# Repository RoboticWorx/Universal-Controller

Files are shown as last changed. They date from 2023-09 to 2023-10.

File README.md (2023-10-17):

# Universal_Controller
Files for my Universal Remote Controller project. 

***(Remember, you can download anything you'd like for yourself but you CAN'T sell or redistribute it. All my work is licensed, thanks!)***

Be sure to go to www.roboticworx.io for detailed tutorials on a variety of projects! Thanks for reading and happy making!

Best regards, 
Justin

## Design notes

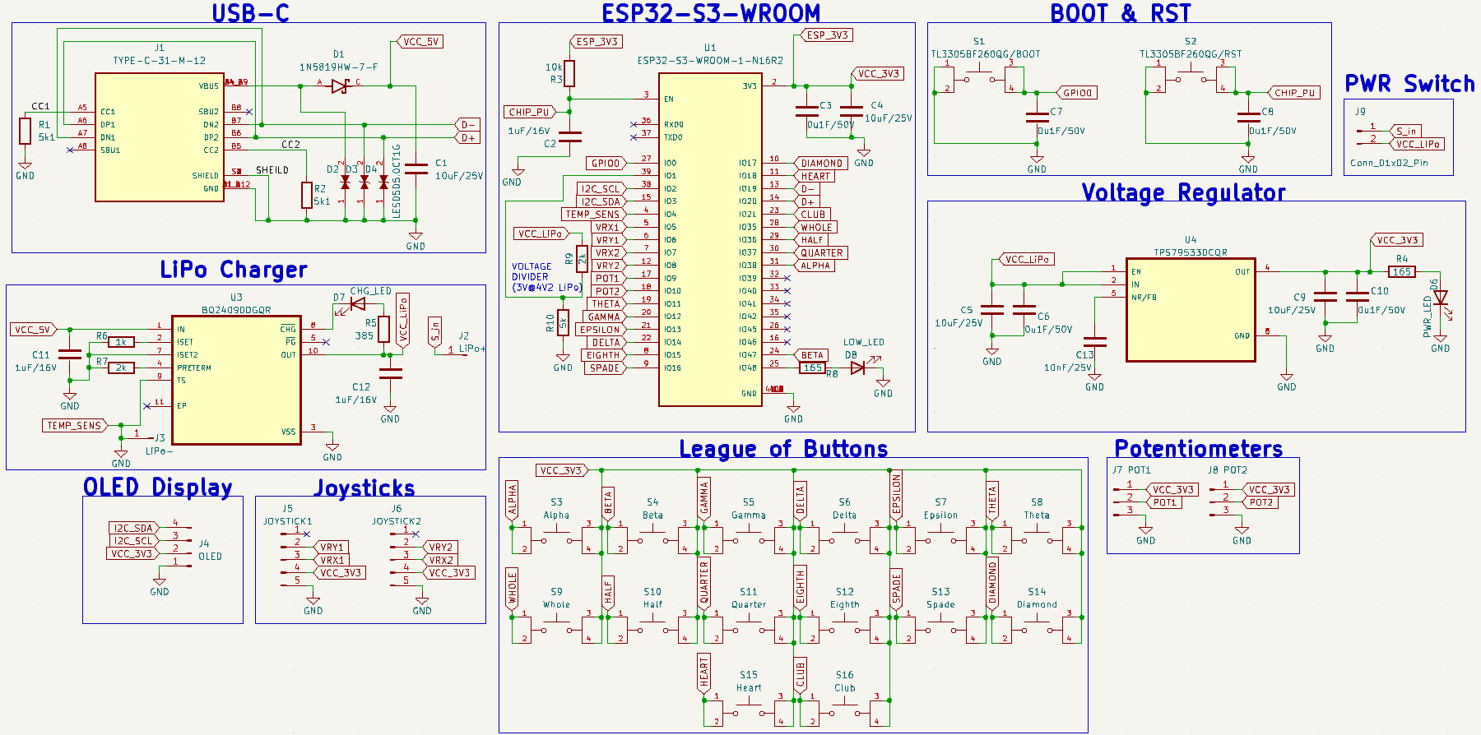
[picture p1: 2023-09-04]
Image_Schematic.png

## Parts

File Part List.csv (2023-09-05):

 | From Digikey
# | QUANTITY | PART NUMBER | MANUFACTURER PART NUMBER | DESCRIPTION | UNIT PRICE
1 | 1 | 296-13810-1-ND | TPS79533DCQR | IC REG LIN 3.3V 500MA SOT223-6 | $2.68
2 | 1 | 478-KGM15AR71H103KTCT-ND | KGM15AR71H103KT | CAP CER 10000PF 50V X7R 0603 | $0.01
3 | 1 | 296-38875-1-ND | BQ24090DGQR | IC BATT CHG LI-ION 1CELL 10MSOP | $1.26
4 | 16 | EG5354CT-ND | TL3305BF260QG | SWITCHES | $0.23
5 | 2 | RG16P2.0KBCT-ND | RG1608P-202-B-T5 | RES SMD 2K OHM 0.1% 1/10W 0603 | $0.35
6 | 1 | 13-RT0603BRE075KLCT-ND | RT0603BRE075KL | RES 5K OHM 0.1% 1/10W 0603 | $0.28
7 | 1 | 754-1721-ND | WP710A10ID5V | LED RED DIFFUSED T-1 T/H | $0.33
8 | 1 | 13-RC0603FR-13390RLCT-ND | RC0603FR-13390RL | RES 390 OHM 1% 1/10W 0603 | $0.01
9 | 1 | 1965-ESP32-S3-WROOM-1-N4R8CT-ND | ESP32-S3-WROOM-1-N4R8 | RF TXRX MODULE BT PCB TRACE SMD | $3.35
10 | 3 | 1276-1019-1-ND | CL10B105KO8NNNC | CAP CER 1UF 16V X7R 0603 | $0.01
11 | 2 | P5.1KDACT-ND | ERA-6AEB512V | RES 5.1K OHM 0.1% 1/8W 0805 | $0.14
12 | 2 | 13-RC0805FR-13180RLCT-ND | RC0805FR-13180RL | RES 180 OHM 1% 1/8W 0805 | $0.01
13 | 4 | 1276-1096-1-ND | CL21A106KOQNNNE | CAP CER 10UF 16V X5R 0805 | $0.03
14 | 1 | RNCP0603FTD10K0CT-ND | RNCP0603FTD10K0 | 10kohm Resistor RES 10K OHM 1% 1/8W 0603 | $0.02
15 | 1 | RNCP0603FTD1K00CT-ND | RNCP0603FTD1K00 | RES 1K OHM 1% 1/8W 0603 | $0.10
 | From LCSC Electronics
16 | 5 | C513772 | CS1005X7R104K500NR | 50V 100nF Capacitor ±10% 0402 Multilayer Ceramic Capacitors MLCC - SMD/SMT ROHS | $0.00
17 | 1 | C82544 | 1N5819HW-7-F | Diode 40V 450mV@1A 1A SOD-123 Schottky Barrier Diodes (SBD) ROHS | $0.02
18 | 3 | C383211 | LESD5D5.0CT1G | Zener Diode 5.6V 18.6V 5V Bi-Directional SOD-523 ESD Protection Devices ROHS | $0.02
19 | 1 | C2765186 | TYPE-C 16PIN 2MD(073) | USB-C Connector 5A 1 Surface Mount 16P Female -25℃~+85℃ Type-C SMD USB Connectors ROHS | $0.05
 | From Amazon
 | In article BOM

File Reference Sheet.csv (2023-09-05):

Reference | Value | Footprint | Datasheet | SNAPEDA_PN | STANDARD | Qty
C1, C4, C5, C9 | 10uF/16V | Capacitor_SMD:C_0805_2012Metric_Pad1.18x1.45mm_HandSolder | ~ |  |  | 4
C2, C11, C12 | 1uF/16V | Capacitor_SMD:C_0603_1608Metric_Pad1.08x0.95mm_HandSolder | ~ |  |  | 3
C3, C6-C8, C10 | 0u1F/50V | Capacitor_SMD:C_0201_0603Metric_Pad0.64x0.40mm_HandSolder | ~ |  |  | 5
C13 | 10nF/25V | Capacitor_SMD:C_0201_0603Metric_Pad0.64x0.40mm_HandSolder | ~ |  |  | 1
D1 | 1N5819HW-7-F | MyParts:SOD3715X145N |  |  | IPC-7351B | 1
D2-D4 | LESD5D5.0CT1G | MyParts:TVS_LESD5D5.0CT1G |  |  | Manufacturer Recommendations | 3
D6 | PWR_LED | LED_THT:LED_D3.0mm | ~ |  |  | 1
D7 | CHG_LED | LED_THT:LED_D3.0mm | ~ |  |  | 1
D8 | LOW_LED | LED_THT:LED_D3.0mm | ~ |  |  | 1
J1 | TYPE-C-31-M-12 | MyParts:HRO_TYPE-C-31-M-12 |  | TYPE-C-31-M-12 | Manufacturer Recommendations | 1
J2 | LiPo+ | Connector_PinHeader_2.54mm:PinHeader_1x01_P2.54mm_Vertical | ~ |  |  | 1
J3 | LiPo- | Connector_PinHeader_2.54mm:PinHeader_1x01_P2.54mm_Vertical | ~ |  |  | 1
J4 | OLED | Connector_PinHeader_2.54mm:PinHeader_1x04_P2.54mm_Vertical | ~ |  |  | 1
J5 | JOYSTICK1 | Connector_PinHeader_2.54mm:PinHeader_1x05_P2.54mm_Vertical | ~ |  |  | 1
J6 | JOYSTICK2 | Connector_PinHeader_2.54mm:PinHeader_1x05_P2.54mm_Vertical | ~ |  |  | 1
J7 | POT1 | Connector_PinHeader_2.54mm:PinHeader_1x03_P2.54mm_Vertical | ~ |  |  | 1
J8 | POT2 | Connector_PinHeader_2.54mm:PinHeader_1x03_P2.54mm_Vertical | ~ |  |  | 1
J9 | Conn_01x02_Pin | Connector_PinHeader_2.54mm:PinHeader_1x02_P2.54mm_Vertical | ~ |  |  | 1
R1, R2 | 5k1 | Resistor_SMD:R_0805_2012Metric_Pad1.20x1.40mm_HandSolder | ~ |  |  | 2
R3 | 10k | Resistor_SMD:R_0805_2012Metric_Pad1.20x1.40mm_HandSolder | ~ |  |  | 1
R4, R8 | 165 | Resistor_SMD:R_0603_1608Metric_Pad0.98x0.95mm_HandSolder | ~ |  |  | 2
R5 | 385 | Resistor_SMD:R_0603_1608Metric_Pad0.98x0.95mm_HandSolder | ~ |  |  | 1
R6 | 1k | Resistor_SMD:R_0805_2012Metric_Pad1.20x1.40mm_HandSolder | ~ |  |  | 1
R7, R9 | 2k | Resistor_SMD:R_0805_2012Metric_Pad1.20x1.40mm_HandSolder | ~ |  |  | 2
R10 | 5k | Resistor_SMD:R_0805_2012Metric_Pad1.20x1.40mm_HandSolder | ~ |  |  | 1
S1 | TL3305BF260QG/BOOT | MyParts:SW_TL3305BF260QG |  | TL3305BF260QG | Manufacturer Recommendations | 1
S2 | TL3305BF260QG/RST | MyParts:SW_TL3305BF260QG |  | TL3305BF260QG | Manufacturer Recommendations | 1
S3 | Alpha (All these switches are the same as RST/BOOT) | MyParts:SW_TL3305BF260QG |  | TL3305BF260QG | Manufacturer Recommendations | 1
S4 | Beta | MyParts:SW_TL3305BF260QG |  | TL3305BF260QG | Manufacturer Recommendations | 1
S5 | Gamma | MyParts:SW_TL3305BF260QG |  | TL3305BF260QG | Manufacturer Recommendations | 1
S6 | Delta | MyParts:SW_TL3305BF260QG |  | TL3305BF260QG | Manufacturer Recommendations | 1
S7 | Epsilon | MyParts:SW_TL3305BF260QG |  | TL3305BF260QG | Manufacturer Recommendations | 1
S8 | Theta | MyParts:SW_TL3305BF260QG |  | TL3305BF260QG | Manufacturer Recommendations | 1
S9 | Whole | MyParts:SW_TL3305BF260QG |  | TL3305BF260QG | Manufacturer Recommendations | 1
S10 | Half | MyParts:SW_TL3305BF260QG |  | TL3305BF260QG | Manufacturer Recommendations | 1
S11 | Quarter | MyParts:SW_TL3305BF260QG |  | TL3305BF260QG | Manufacturer Recommendations | 1
S12 | Eighth | MyParts:SW_TL3305BF260QG |  | TL3305BF260QG | Manufacturer Recommendations | 1
S13 | Spade | MyParts:SW_TL3305BF260QG |  | TL3305BF260QG | Manufacturer Recommendations | 1
S14 | Diamond | MyParts:SW_TL3305BF260QG |  | TL3305BF260QG | Manufacturer Recommendations | 1
S15 | Heart | MyParts:SW_TL3305BF260QG |  | TL3305BF260QG | Manufacturer Recommendations | 1
S16 | Club | MyParts:SW_TL3305BF260QG |  | TL3305BF260QG | Manufacturer Recommendations | 1
U1 | ESP32-S3-WROOM-1-N16R2 | MyParts:XCVR_ESP32-S3-WROOM-1-N16R2 |  |  | Manufacturer Recommendations | 1
U3 | BQ24090DGQR | MyParts:IC_XTR111AIDGQR |  |  |  | 1
U4 | TPS79533DCQR | MyParts:SOT127P706X180-6N |  |  |  | 1

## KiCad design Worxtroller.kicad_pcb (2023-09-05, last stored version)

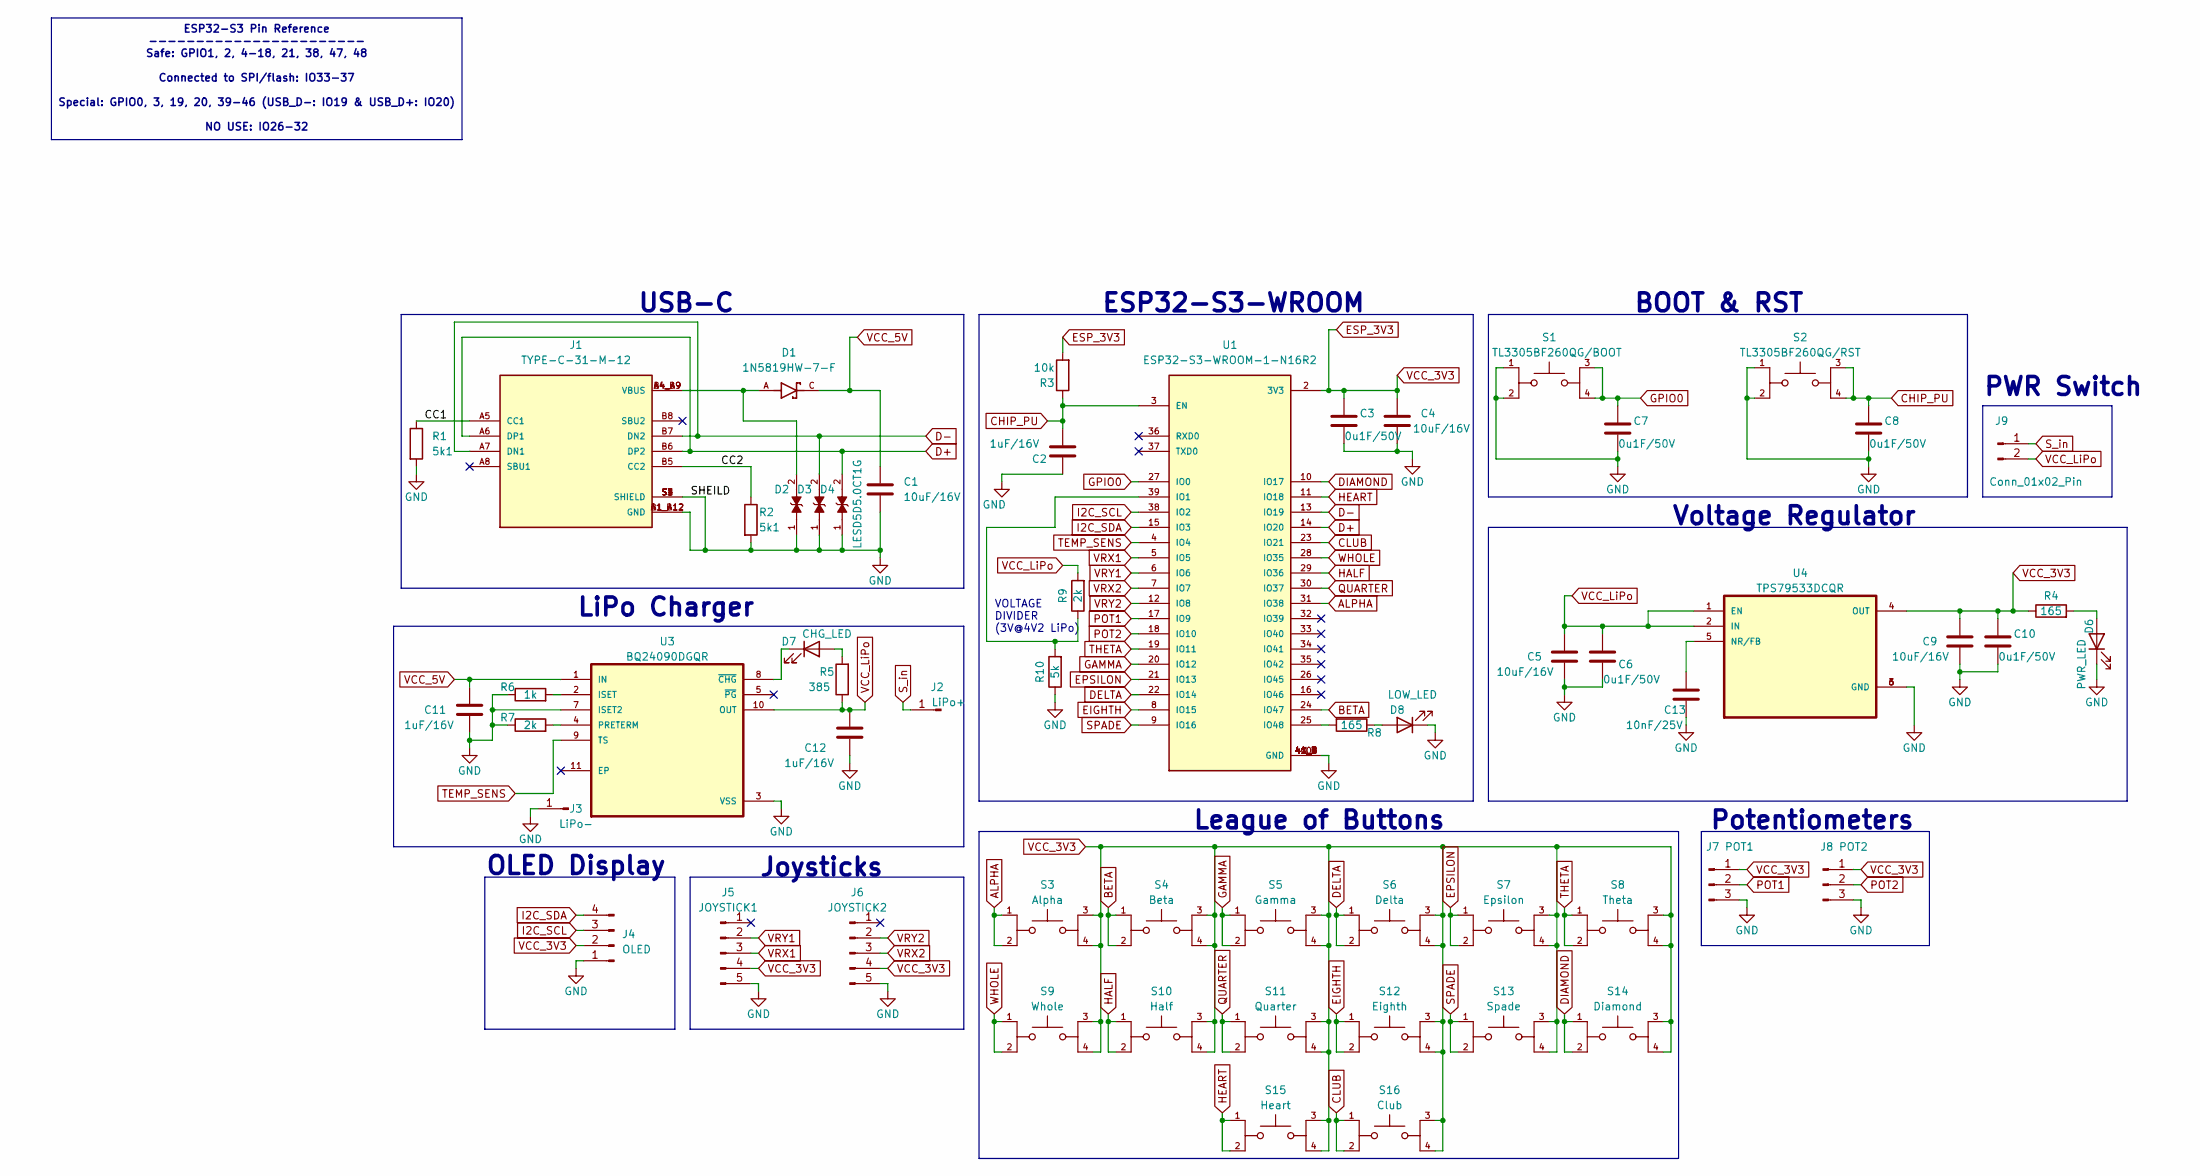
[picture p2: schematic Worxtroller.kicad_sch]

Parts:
C1, C4, C5, C9: 10uF/16V; C_0805_2012Metric_Pad1.18x1.45mm_HandSolder
C2, C11, C12: 1uF/16V; C_0603_1608Metric_Pad1.08x0.95mm_HandSolder
C3, C6, C7, C8, C10: 0u1F/50V; C_0201_0603Metric_Pad0.64x0.40mm_HandSolder
C13: 10nF/25V; C_0201_0603Metric_Pad0.64x0.40mm_HandSolder
D1: 1N5819HW-7-F; SOD3715X145N; PARTREV 18-2
D2, D3, D4: LESD5D5.0CT1G; TVS_LESD5D5.0CT1G; PARTREV O
D6: PWR_LED; LED_D3.0mm
D7: CHG_LED; LED_D3.0mm
D8: LOW_LED; LED_D3.0mm
J1: TYPE-C-31-M-12; HRO_TYPE-C-31-M-12; PARTREV 2020.12.08
J2: LiPo+; PinHeader_1x01_P2.54mm_Vertical
J3: LiPo-; PinHeader_1x01_P2.54mm_Vertical
J4: OLED; PinHeader_1x04_P2.54mm_Vertical
J5: JOYSTICK1; PinHeader_1x05_P2.54mm_Vertical
J6: JOYSTICK2; PinHeader_1x05_P2.54mm_Vertical
J7: POT1; PinHeader_1x03_P2.54mm_Vertical
J8: POT2; PinHeader_1x03_P2.54mm_Vertical
J9: Conn_01x02_Pin; PinHeader_1x02_P2.54mm_Vertical
R1, R2: 5k1; R_0805_2012Metric_Pad1.20x1.40mm_HandSolder
R3: 10k; R_0805_2012Metric_Pad1.20x1.40mm_HandSolder
R4, R8: 165; R_0603_1608Metric_Pad0.98x0.95mm_HandSolder
R5: 385; R_0603_1608Metric_Pad0.98x0.95mm_HandSolder
R6: 1k; R_0805_2012Metric_Pad1.20x1.40mm_HandSolder
R7, R9: 2k; R_0805_2012Metric_Pad1.20x1.40mm_HandSolder
R10: 5k; R_0805_2012Metric_Pad1.20x1.40mm_HandSolder
S1: TL3305BF260QG/BOOT; SW_TL3305BF260QG; PARTREV C
S2: TL3305BF260QG/RST; SW_TL3305BF260QG; PARTREV C
S3: Alpha; SW_TL3305BF260QG; PARTREV C
S4: Beta; SW_TL3305BF260QG; PARTREV C
S5: Gamma; SW_TL3305BF260QG; PARTREV C
S6: Delta; SW_TL3305BF260QG; PARTREV C
S7: Epsilon; SW_TL3305BF260QG; PARTREV C
S8: Theta; SW_TL3305BF260QG; PARTREV C
S9: Whole; SW_TL3305BF260QG; PARTREV C
S10: Half; SW_TL3305BF260QG; PARTREV C
S11: Quarter; SW_TL3305BF260QG; PARTREV C
S12: Eighth; SW_TL3305BF260QG; PARTREV C
S13: Spade; SW_TL3305BF260QG; PARTREV C
S14: Diamond; SW_TL3305BF260QG; PARTREV C
S15: Heart; SW_TL3305BF260QG; PARTREV C
S16: Club; SW_TL3305BF260QG; PARTREV C
U1: ESP32-S3-WROOM-1-N16R2; XCVR_ESP32-S3-WROOM-1-N16R2; PARTREV v1.0
U3: BQ24090DGQR; IC_XTR111AIDGQR
U4: TPS79533DCQR; SOT127P706X180-6N

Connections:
/CC1: J1.A5 (CC1), R1.1
/CC2: J1.B5 (CC2), R2.1
ALPHA: S3.1, S3.2, U1.31 (IO38)
BETA: S4.1, S4.2, U1.24 (IO47)
CHIP_PU: C2.2, C8.1, R3.1, S2.3, S2.4, U1.3 (EN)
CLUB: S16.1, S16.2, U1.23 (IO21)
D+: D4.2, J1.A6 (DP1), J1.B6 (DP2), U1.14 (IO20)
D-: D3.2, J1.A7 (DN1), J1.B7 (DN2), U1.13 (IO19)
DELTA: S6.1, S6.2, U1.22 (IO14)
DIAMOND: S14.1, S14.2, U1.10 (IO17)
EIGHTH: S12.1, S12.2, U1.8 (IO15)
EPSILON: S7.1, S7.2, U1.21 (IO13)
ESP_3V3: C3.1, C4.1, C9.1, C10.1, J4.2, J5.4, J6.4, J7.1, J8.1, R3.2, R4.1, S3.3, S3.4, S4.3, S4.4, S5.3, S5.4, S6.3, S6.4, S7.3, S7.4, S8.3, S8.4, S9.3, S9.4, S10.3, S10.4, S11.3, S11.4, S12.3, S12.4, S13.3, S13.4, S14.3, S14.4, S15.3, S15.4, S16.3, S16.4, U1.2 (3V3), U4.4 (OUT)
GAMMA: S5.1, S5.2, U1.20 (IO12)
GPIO0: C7.1, S1.3, S1.4, U1.27 (IO0)
HALF: S10.1, S10.2, U1.29 (IO36)
HEART: S15.1, S15.2, U1.11 (IO18)
I2C_SCL: J4.3, U1.38 (IO2)
I2C_SDA: J4.4, U1.15 (IO3)
unnamed: D1.A, D2.2, J1.A4_B9 (VBUS), J1.B4_A9 (VBUS)
unnamed: D6.2 (A), R4.2
unnamed: D7.2 (A), R5.2
unnamed: D7.1 (K), U3.8 (~CHG)
unnamed: D8.2 (A), R8.1
unnamed: R9.1, R10.2, U1.39 (IO1)
unnamed: R8.2, U1.25 (IO48)
unnamed: R6.2, U3.2 (ISET)
unnamed: R7.2, U3.4 (PRETERM)
unnamed: C13.1, U4.5 (NR/FB)
POT1: J7.2, U1.17 (IO9)
POT2: J8.2, U1.18 (IO10)
QUARTER: S11.1, S11.2, U1.30 (IO37)
SENSE: U1.4 (IO4), U3.9 (TS)
SPADE: S13.1, S13.2, U1.9 (IO16)
S_in: J2.1, J9.1
TEMP_SENS: C1.2, C2.1, C3.2, C4.2, C5.2, C6.2, C7.2, C8.2, C9.2, C10.2, C11.1, C12.1, C13.2, D2.1, D3.1, D4.1, D6.1 (K), D8.1 (K), J1.A1_B12 (GND), J1.B1_A12 (GND), J1.S1 (SHIELD), J1.S2 (SHIELD), J1.S3 (SHIELD), J1.S4 (SHIELD), J3.1, J4.1, J5.5, J6.5, J7.3, J8.3, R1.2, R2.2, R6.1, R7.1, R10.1, S1.1, S1.2, S2.1, S2.2, U1.1 (GND), U1.40 (GND), U1.41_1 (GND), U1.41_2 (GND), U1.41_3 (GND), U1.41_4 (GND), U1.41_5 (GND), U1.41_6 (GND), U1.41_7 (GND), U1.41_8 (GND), U1.41_9 (GND), U1.41_10, U1.41_11, U1.41_12, U1.41_13, U1.41_14, U1.41_15, U1.41_16, U1.41_17, U1.41_18, U1.41_19, U1.41_20, U1.41_21, U3.3 (VSS), U3.7 (ISET2), U3.11 (EP), U3.12, U3.13, U3.14, U3.15, U3.16, U4.3 (GND), U4.6 (GND)
THETA: S8.1, S8.2, U1.19 (IO11)
VCC_5V: C1.1, C11.2, D1.C, U3.1 (IN)
VCC_LiPo: C5.1, C6.1, C12.2, J9.2, R5.1, R9.2, U3.10 (OUT), U4.1 (EN), U4.2 (IN)
VRX1: J5.3, U1.5 (IO5)
VRX2: J6.3, U1.7 (IO7)
VRY1: J5.2, U1.6 (IO6)
VRY2: J6.2, U1.12 (IO8)
WHOLE: S9.1, S9.2, U1.28 (IO35)

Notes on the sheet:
ESP32-S3 Pin Reference ----------------------- Safe: GPIO1, 2, 4-18, 21, 38, 47, 48 Connected to SPI/flash: IO33-37 Special: GPIO0, 3, 19, 20, 39-46 (USB_D-: IO19 & USB_D+: IO20) NO USE: IO26-32
ESP32-S3-WROOM
OLED Display
Voltage Regulator
LiPo Charger
Joysticks
BOOT & RST
Potentiometers
VOLTAGE DIVIDER (3V@4V2 LiPo)
League of Buttons
PWR Switch
USB-C

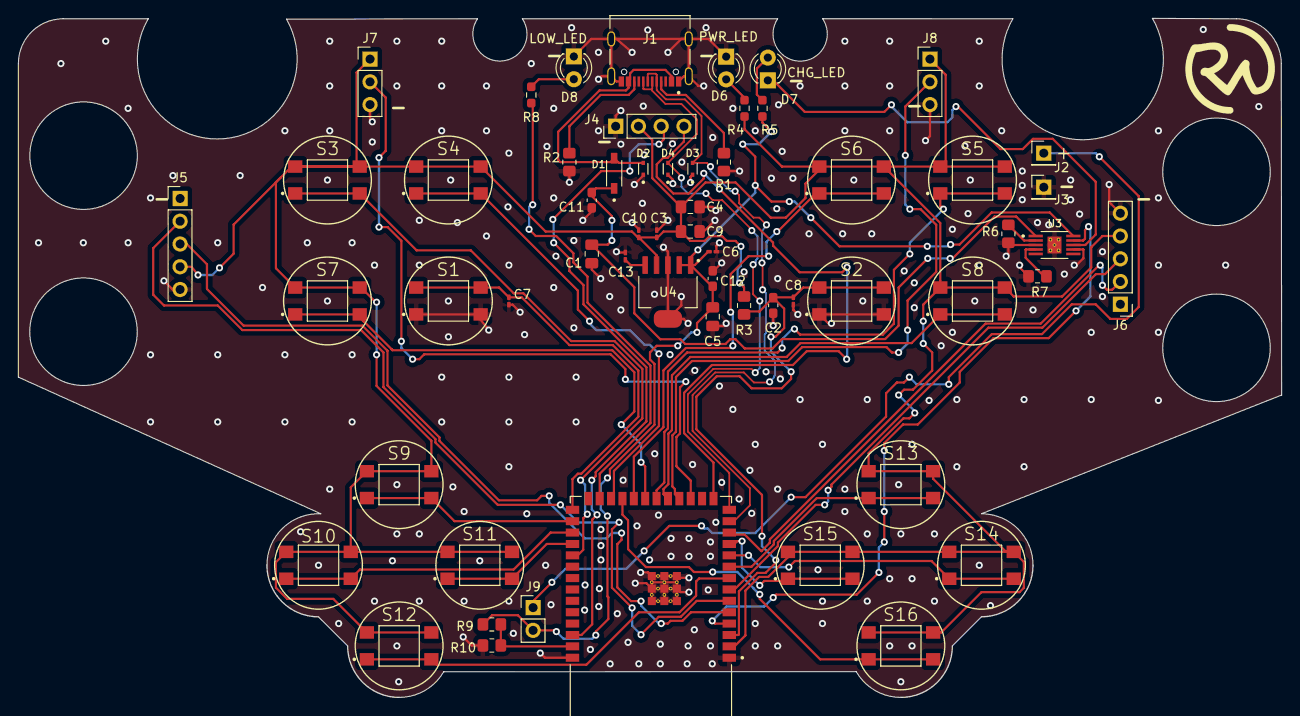
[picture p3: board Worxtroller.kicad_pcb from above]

Board: 2 copper layers, 141.0 x 75.8 mm, 58 parts (0 on the bottom side), 44 nets.

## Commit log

2023-09-04 Electrical Schematic Image
2023-09-04 Reference Sheet
    [Reference Sheet.csv]
2023-09-04 Part List
    [Part List.csv]
2023-09-05 Update Reference Sheet.csv
    [Reference Sheet.csv]
2023-09-05 Part List (BOM)
    [Part List.csv]
2023-09-05 Gerber File for PCB Fabrication
2023-09-05 Editable KiCad files
    [Worxtroller.kicad_pcb, Worxtroller.kicad_sch]
2023-09-05 Update Part List.csv
    [Part List.csv]
2023-09-06 Universal Controller Fabrication File (GERBER)
2023-09-06 U.C. Editable KiCad Files
